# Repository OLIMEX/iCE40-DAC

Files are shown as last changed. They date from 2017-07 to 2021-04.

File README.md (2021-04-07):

# iCE40-DAC
Extension module for iCE40HX1K-EVB or iCE40HX8K-EVB.

Adds fast Digital-Analog-Converter (DAC) functionality to the main board.

You can effectively use up to 4 x iCE40-DAC with a single EVB board (or up to 2 x iCE40-DAC when you have iCE40-IO connected to the same bus).

You can use the exported PDFs to access the schematic or the bill of materials. 

We used the latest KiCad night builds to create the design. Please use a new version KiCad to open it. 

License information should be found in LICENSE.txt

## Hardware revision changes:

### Hardware revision A1

- Changed resistor changing R9 to 0R (down from 10k), this is done because EXTIO was not properly grounded leading to wrong levels

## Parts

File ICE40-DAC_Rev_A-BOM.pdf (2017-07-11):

ICE40-DAC_Rev_A-BOM | 30.03.2016
Quantity Designation | Package | Designator
1 | BH34R | BH34R | GPIO_Out1
2 | 22uF/6.3V/0603 | C_0603 | C1,C4
6 | 100nF | C_0402 | C2,C5,C6,C10,C3,C13
2 | 49.9R/1% | R_0603 | R11,R12
1 | 2k/1% | R_0402 | R10
2 | 10k | R_0402 | R4,R9
1 | 22R | R_0402 | R6
2 | FB0805/600R/2A | L_0805 | L1,L2
1 | SN74ACT244DWR(SOIC-20) | SOIC20 | U2
1 | THS5641AIDW(SOIC28) | SOIC28-300 | U1
1 | IDC34R | IDC34R_PCB | GPIO_In1
1 | BNC-JD11-50-LF | BNC-JD11-50-LF | IOUT1
1 | Soldered | SJ | CLK_E1
3 | Opened | SJ | CLK_E2,CLK_E3,CLK_E4
1 | NA(HN1x2) | HN1x2 | IOUT2
1 | NA(BC817-40(SOT-23)) | SOT23 | Q1
2 | NA(22uF/6.3V/0603) | C_0603 | C8,C7
3 | NA | C_0402 | C12,C9,C11
6 | NA | R_0402 | R1,R2,R3,R5,R7,R8
1 | NA(TLV431BSN1T1G(SOT23-3)) | SOT-23-3 | SR1

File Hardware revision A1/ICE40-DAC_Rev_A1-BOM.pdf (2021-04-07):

02/19/2021 | ICE40-DAC_Rev_A1-BOM | 16:56:18
Quantity | Designation | Package | Designator
1 | 0R | R_0402 | R9
1 | 22R | R_0402 | R6
2 | 49.9R/1% | R_0603 | R11,R12
1 | 2k/1% | R_0402 | R10
1 | 10k | R_0402 | R4
2 | FB0805/600R/2A | L_0805 | L1,L2
6 | 100nF | C_0402 | C2,C3,C5,C6,C10,C13
2 | 22uF/6.3V/0603 | C_0603 | C1,C4
1 | SN74ACT244DWR(SOIC-20) | SOIC20 | U2
1 | THS5641AIDW(SOIC28) | SOIC28-300 | U1
1 | BH34R | BH34R | GPIO_Out1
1 | IDC34R | IDC34R_PCB | GPIO_In1
1 | BNC-JD11-50-LF | BNC-JD11-50-LF | IOUT1
1 | Soldered | SJ | CLK_E1
3 | Opened | SJ | CLK_E2,CLK_E3,CLK_E4
1 | NA(HN1x2) | HN1x2 | IOUT2
1 | NA(BC817-40(SOT-23)) | SOT23 | Q1
2 | NA(22uF/6.3V/0603) | C_0603 | C7,C8
3 | NA | C_0402 | C9,C11,C12
6 | NA | R_0402 | R1,R2,R3,R5,R7,R8
1 | NA(TLV431BSN1T1G(SOT23-3)) | SOT-23-3 | SR1

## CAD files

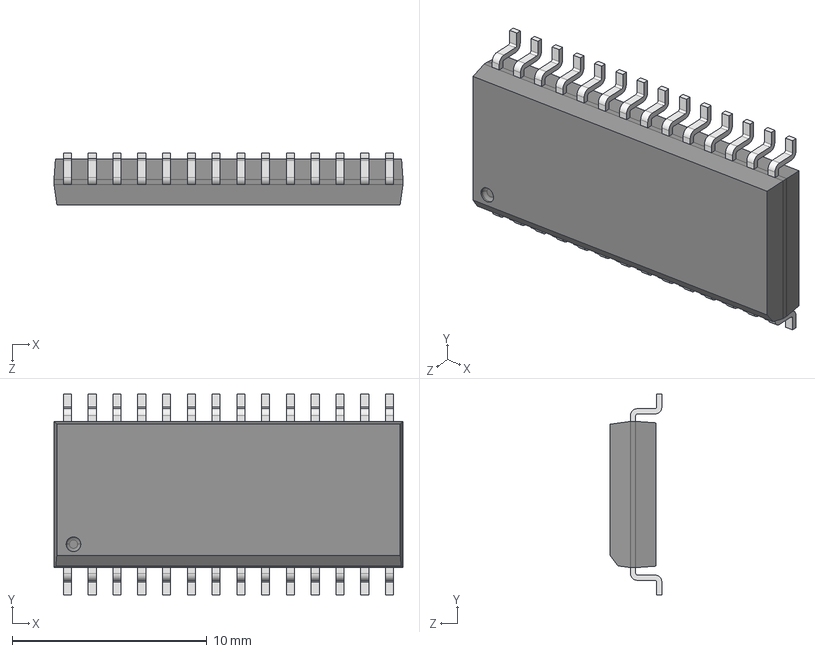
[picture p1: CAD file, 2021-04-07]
Hardware revision A1/3d/SOIC28-300.step
17.9 x 10.3 x 2.65 mm

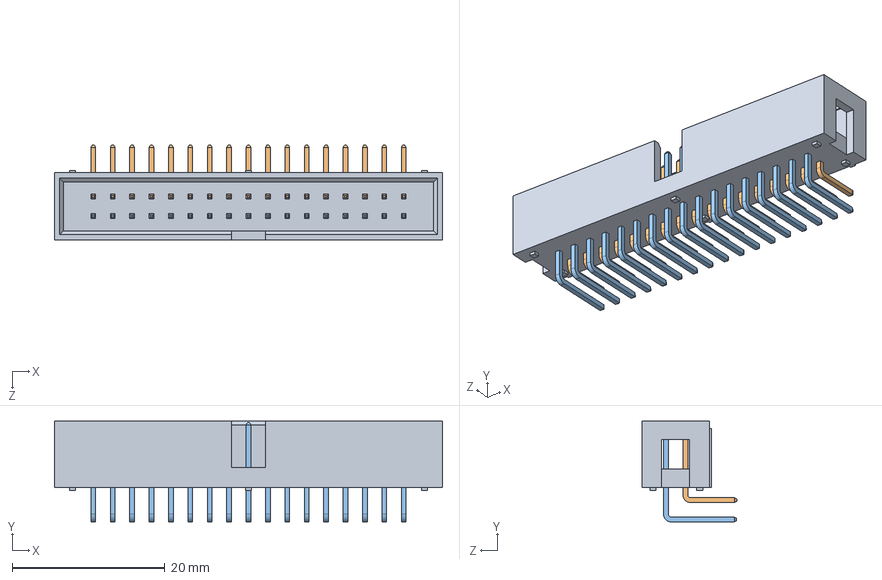
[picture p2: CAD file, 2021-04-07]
Hardware revision A1/3d/BH34R_CH87342H100.STEP
50.8 x 13.2 x 12.4 mm
CH87 BASE_34
H TYPEµuPIN x 17
H TYPEªøPIN x 17

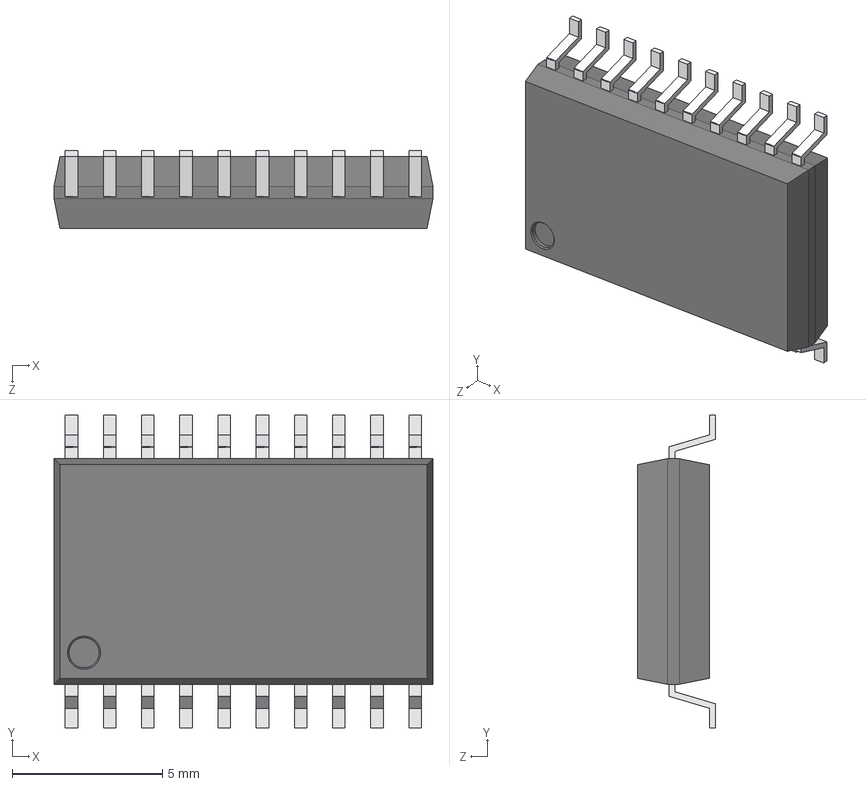
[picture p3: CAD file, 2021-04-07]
Hardware revision A1/3d/SOIC_20-300.STEP
12.6 x 10.4 x 2.60 mm
User Library-SOIC_20-300_pino1
User Library-SOIC_20-300_pino002
User Library-SOIC_20-300_pino003
User Library-SOIC_20-300_pino004
User Library-SOIC_20-300_pino005
User Library-SOIC_20-300_pino006
User Library-SOIC_20-300_pino007
User Library-SOIC_20-300_pino008
User Library-SOIC_20-300_pino009
User Library-SOIC_20-300_pino010
User Library-SOIC_20-300_pino015
User Library-SOIC_20-300_pino016
User Library-SOIC_20-300_pino017
User Library-SOIC_20-300_pino018
User Library-SOIC_20-300_pino019
User Library-SOIC_20-300_pino020
User Library-SOIC_20-300_pino021
User Library-SOIC_20-300_pino022
User Library-SOIC_20-300_pino023
User Library-SOIC_20-300_pino024
User Library-SOIC_20-300_body_finished

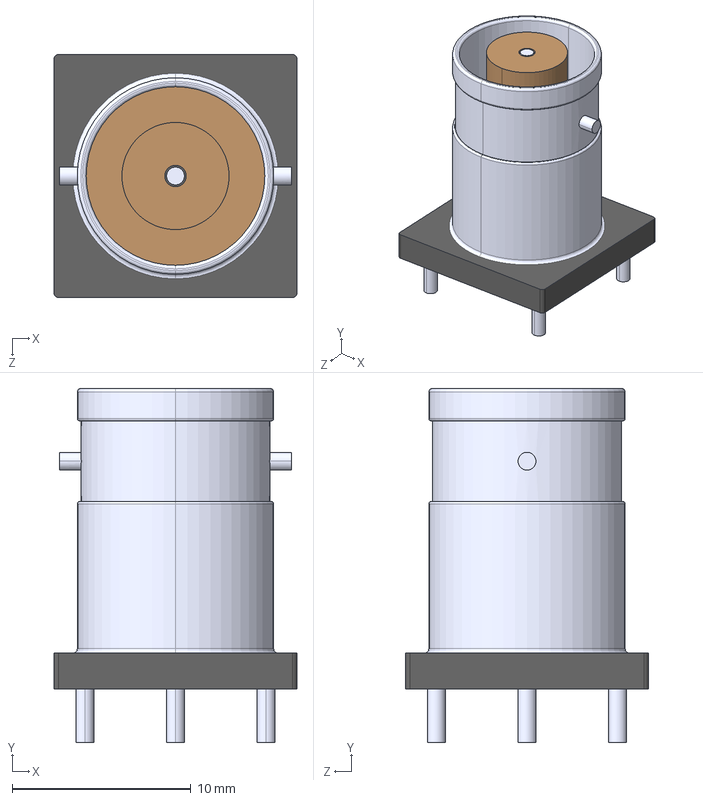
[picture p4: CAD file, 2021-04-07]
Hardware revision A1/3d/CircuitWorks-BNC.step
13.6 x 19.8 x 13.6 mm

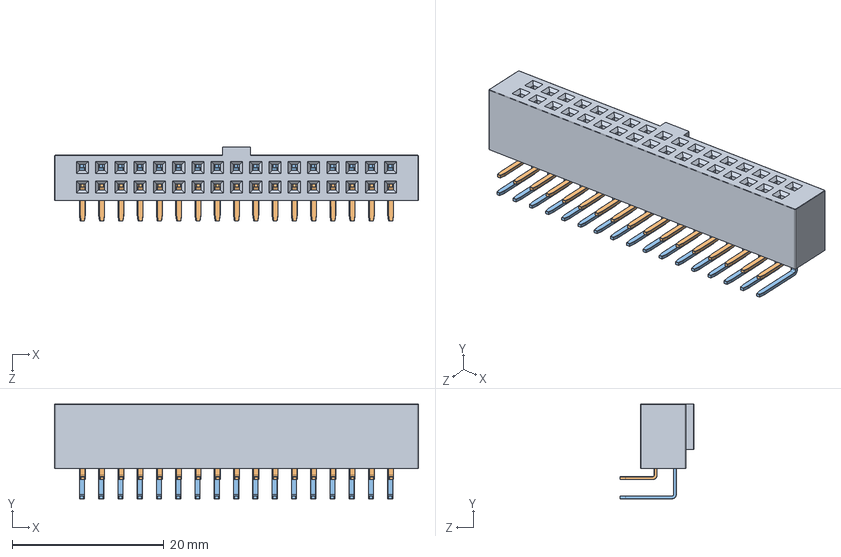
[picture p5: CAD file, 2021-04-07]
Hardware revision A1/3d/IDC34R-PCB_CB94342H100.STEP
48.0 x 12.5 x 9.81 mm
cb94 BASE_34
CB91-t2 x 17
CB91-t3 x 17

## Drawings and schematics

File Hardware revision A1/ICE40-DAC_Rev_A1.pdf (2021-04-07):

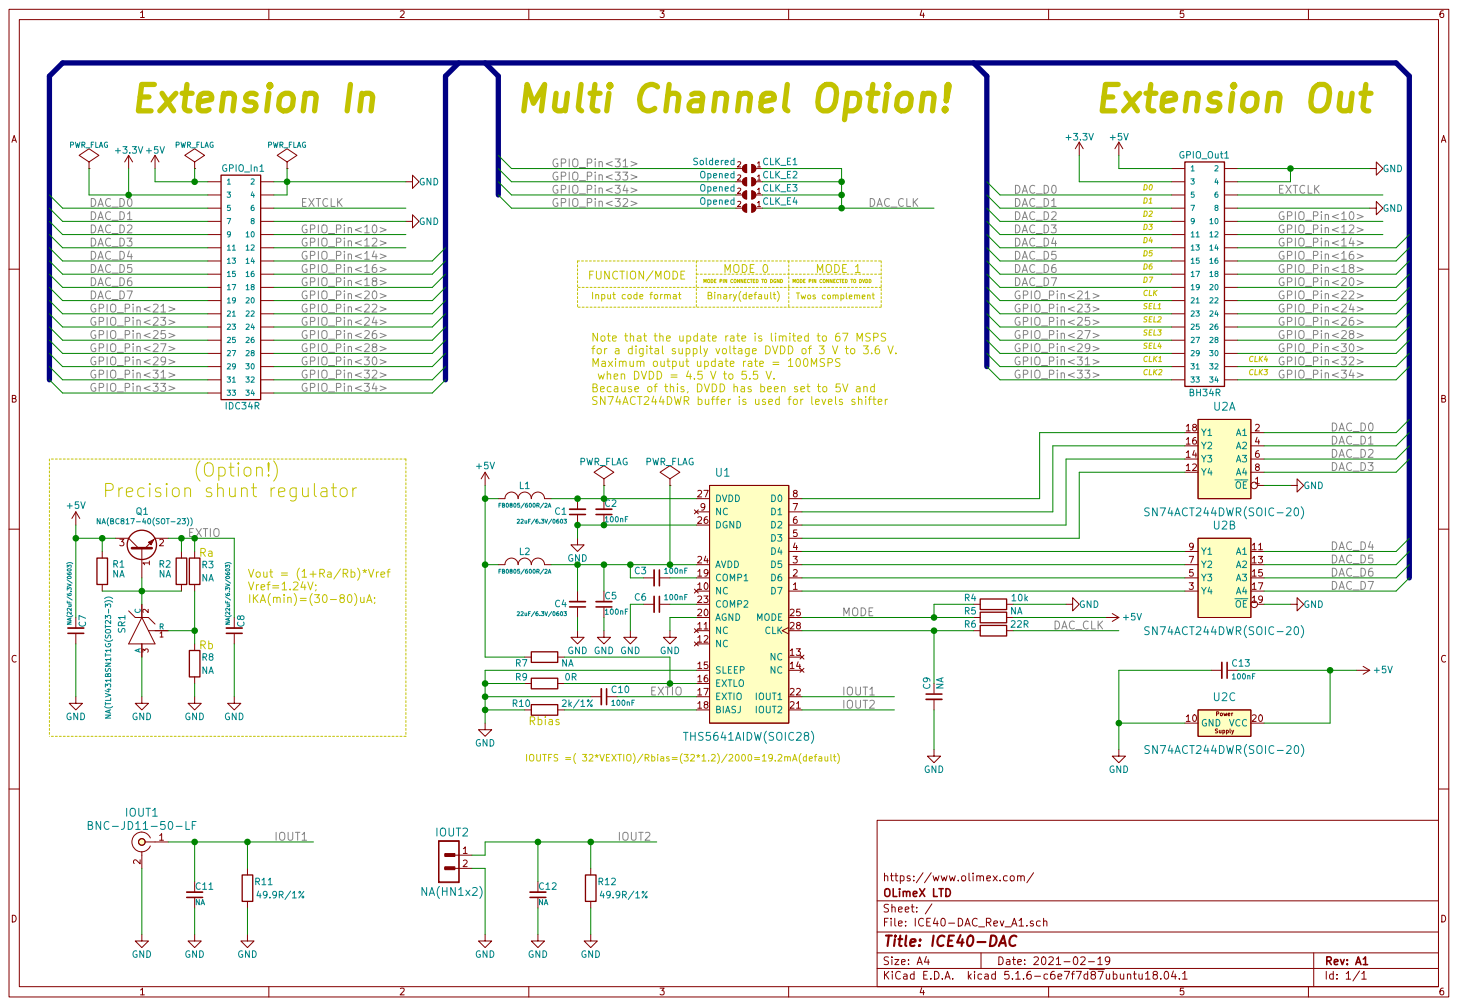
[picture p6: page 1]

Note that the update rate is limited to 67 MSPS
for a digital supply voltage DVDD of 3 V to 3.6 V.
Maximum output update rate = 100MSPS
when DVDD = 4.5 V to 5.5 V. Because of this, DVDD has been set to 5V and

(Option!)
Precision shunt regulator Rb

https://www.olimex.com/ GND

Vout = (1+Ra/Rb)*Vref
Vref=1.24V;
IKA(min)=(30-80)uA;

IOUT2

IOUTFS =( 32*VEXTIO)/Rbias=(32*1.2)/2000=19.2mA(default)

File: ICE40-DAC_Rev_A1.sch Sheet: / OLimeX LTD

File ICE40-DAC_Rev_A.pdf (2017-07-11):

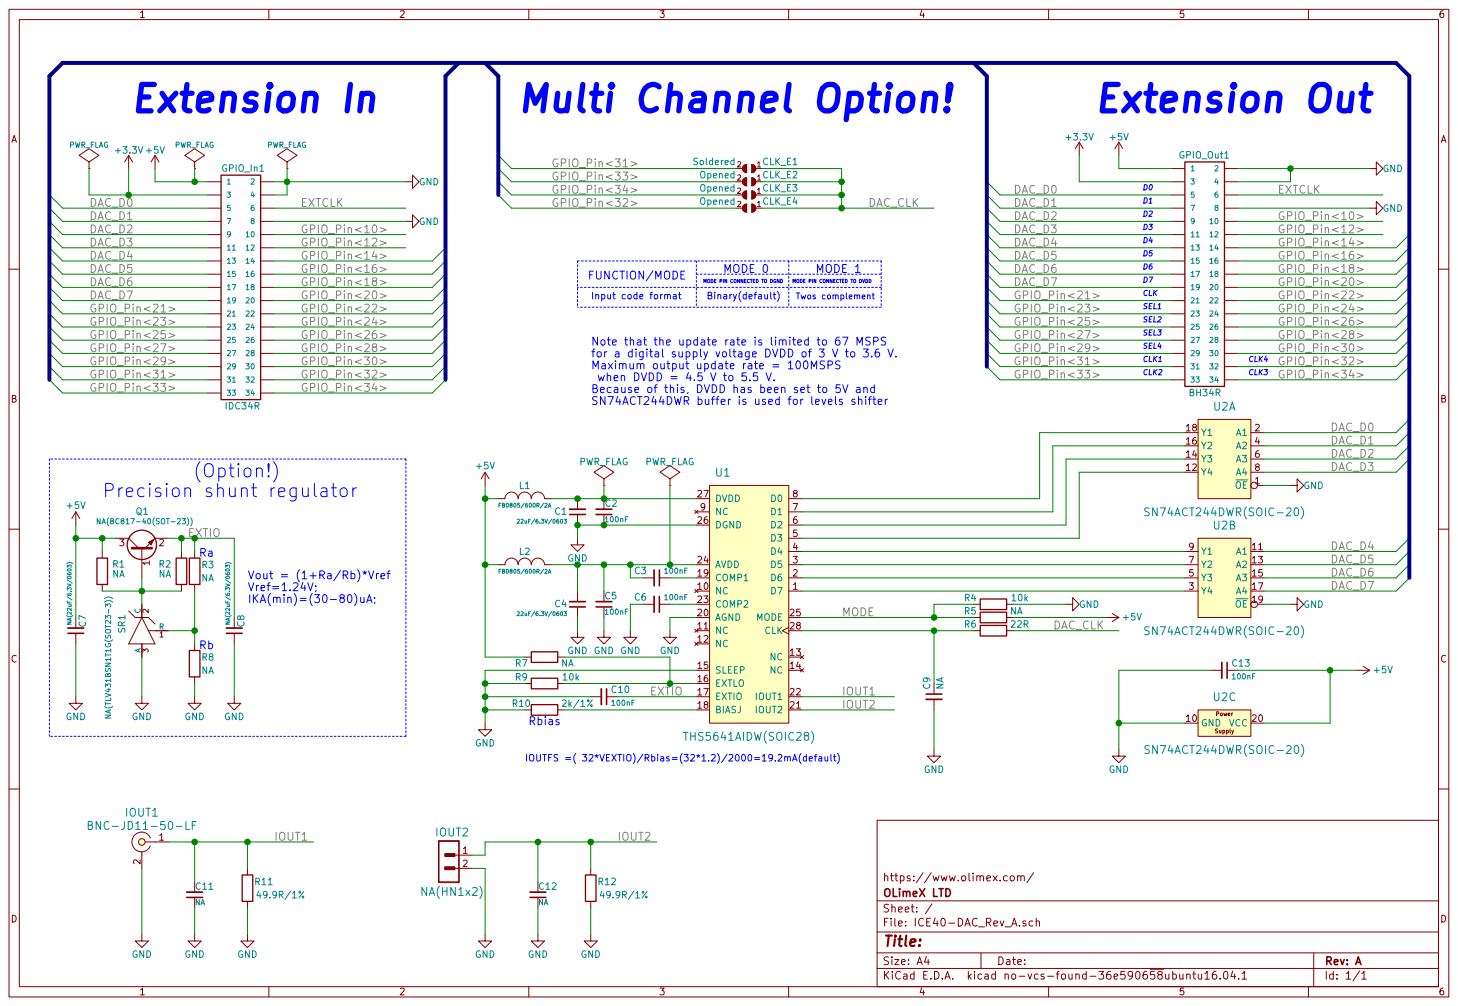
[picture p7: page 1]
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

SN74ACT244DWR buffer is used for levels shifter Rbias

IKA(min)=(30-80)uA; Ra Rb GND

IOUT2

IOUTFS =( 32*VEXTIO)/Rbias=(32*1.2)/2000=19.2mA(default)

https://www.olimex.com/
File: ICE40-DAC_Rev_A.sch Sheet: / OLimeX LTD

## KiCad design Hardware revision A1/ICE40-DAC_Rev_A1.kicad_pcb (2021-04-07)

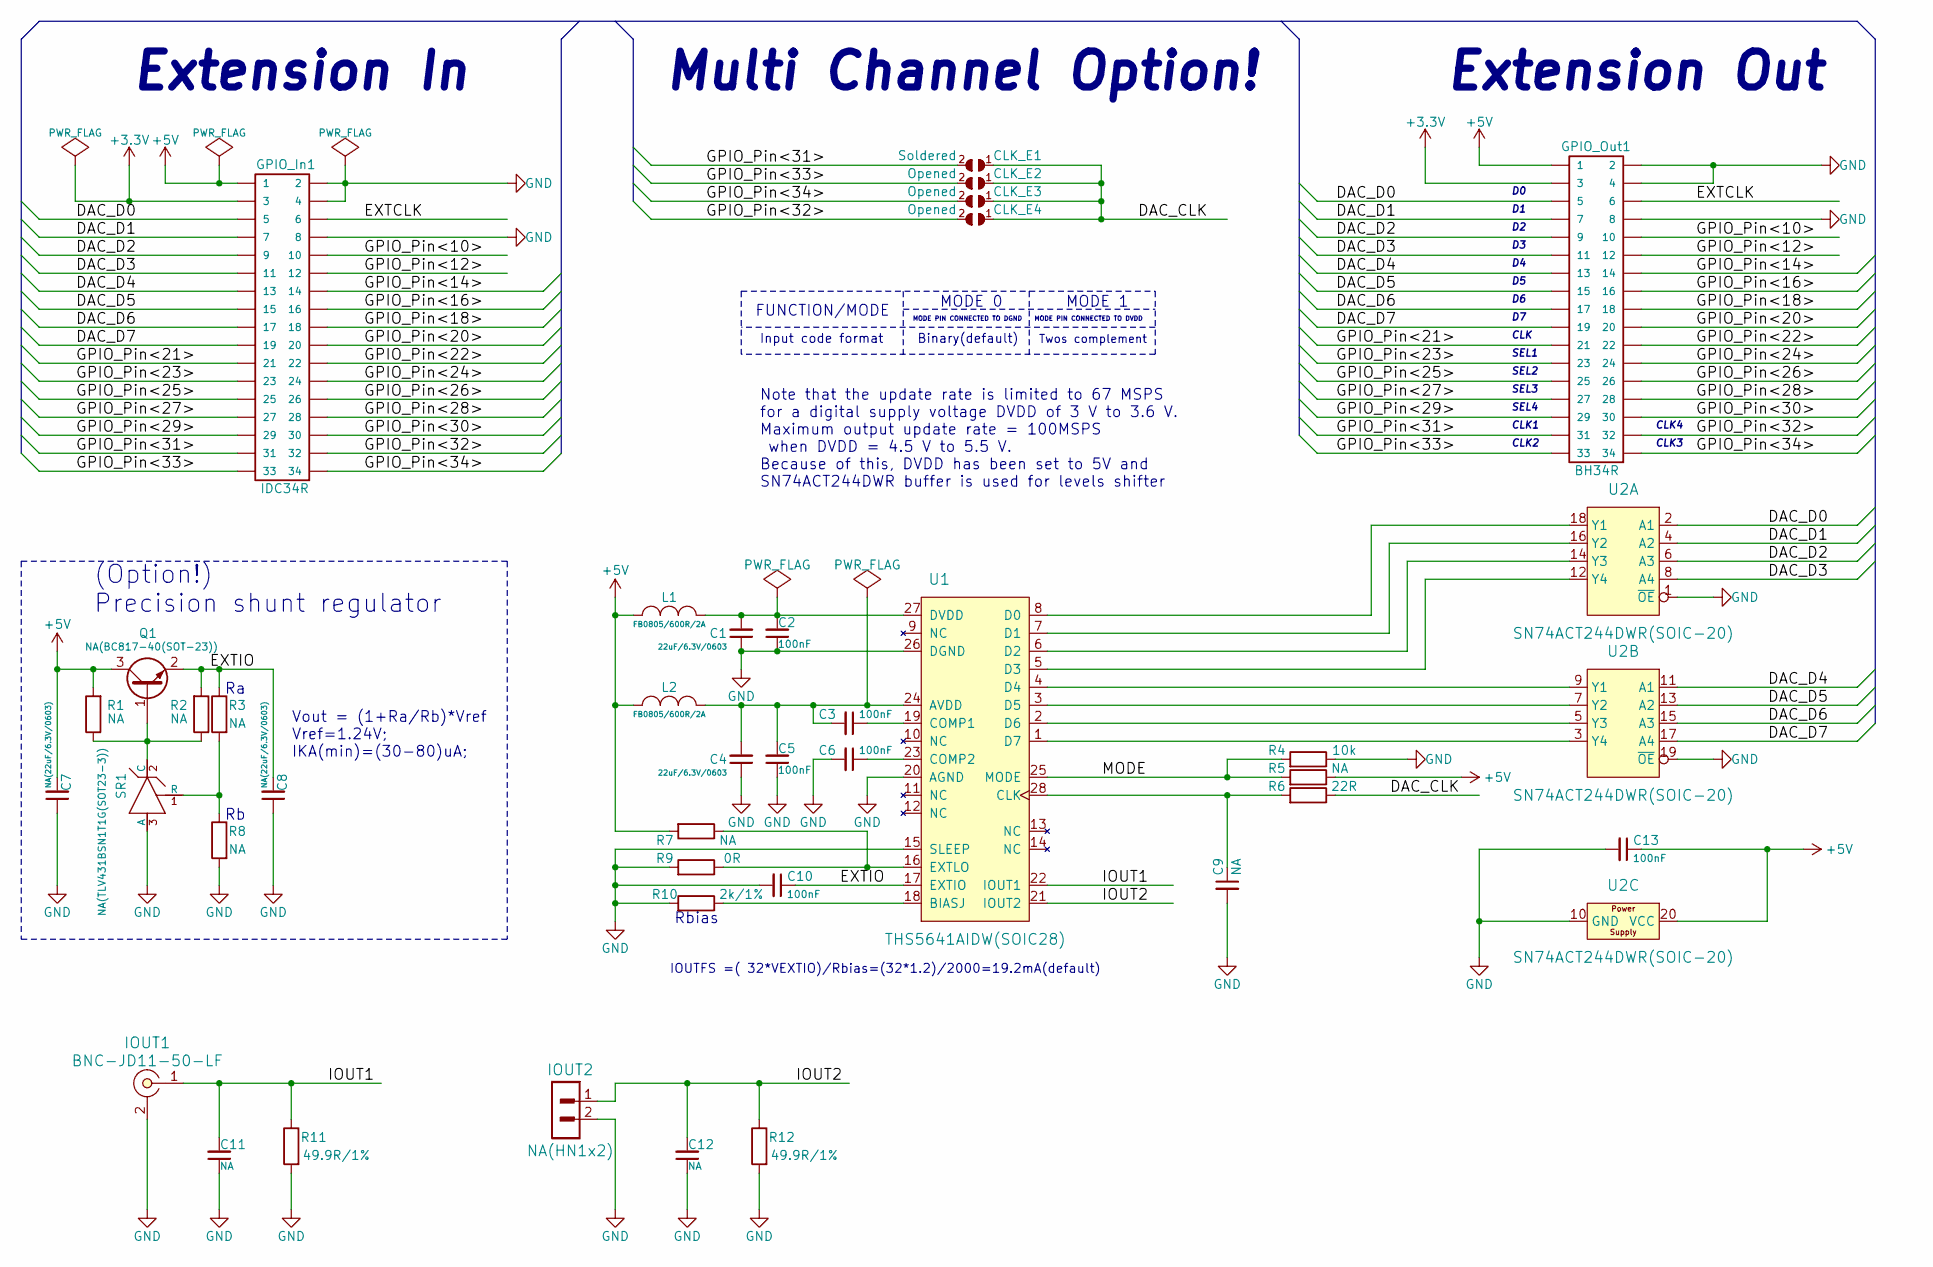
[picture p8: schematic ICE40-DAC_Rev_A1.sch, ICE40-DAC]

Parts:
C1, C4: 22uF/6.3V/0603; C_0603_5MIL_DWS
C2, C3, C5, C6, C10, C13: 100nF; C_0402_5MIL_DWS
C7, C8: NA(22uF/6.3V/0603); C_0603_5MIL_DWS
C9, C11, C12: NA; C_0402_5MIL_DWS
CLK_E1: Soldered; SJ
CLK_E2, CLK_E3, CLK_E4: Opened; SJ
GPIO_In1: IDC34R; IDC34R_PCB
GPIO_Out1: BH34R
IOUT1: BNC-JD11-50-LF; BNC-JD11-50-LF_1-IN_2-GND
IOUT2: NA(HN1x2); HN1x2
L1, L2: FB0805/600R/2A; L_0805_5MIL_DWS
Q1: NA(BC817-40(SOT-23)); SOT23
R1, R2, R3, R5, R7, R8: NA; R_0402_5MIL_DWS
R4: 10k; R_0402_5MIL_DWS
R6: 22R; R_0402_5MIL_DWS
R9: 0R; R_0402_5MIL_DWS
R10: 2k/1%; R_0402_5MIL_DWS
R11, R12: 49.9R/1%; R_0603_5MIL_DWS
SR1: NA(TLV431BSN1T1G(SOT23-3)); SOT-23
U1: THS5641AIDW(SOIC28); SOIC28-300
U2: SN74ACT244DWR(SOIC-20); SOIC20_300mil

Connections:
+3V3: GPIO_In1.3, GPIO_Out1.3
+5V: C7.2, C13.1, GPIO_In1.1, GPIO_Out1.1, L1.2, L2.1, Q1.3 (C), R1.2, R5.1, R7.2, U2.20 (VCC)
/DAC_CLK: CLK_E1.1, CLK_E2.1, CLK_E3.1, CLK_E4.1, R6.1
/DAC_D0: GPIO_In1.5, GPIO_Out1.5, U2.2 (A1)
/DAC_D1: GPIO_In1.7, GPIO_Out1.7, U2.4 (A2)
/DAC_D2: GPIO_In1.9, GPIO_Out1.9, U2.6 (A3)
/DAC_D3: GPIO_In1.11, GPIO_Out1.11, U2.8 (A4)
/DAC_D4: GPIO_In1.13, GPIO_Out1.13, U2.11 (A1)
/DAC_D5: GPIO_In1.15, GPIO_Out1.15, U2.13 (A2)
/DAC_D6: GPIO_In1.17, GPIO_Out1.17, U2.15 (A3)
/DAC_D7: GPIO_In1.19, GPIO_Out1.19, U2.17 (A4)
/EXTCLK: GPIO_In1.6, GPIO_Out1.6
/EXTIO: C8.2, C10.1, Q1.2 (E), R2.2, R3.1, U1.17 (EXTIO)
/GPIO_Pin<10>: GPIO_In1.10, GPIO_Out1.10
/GPIO_Pin<12>: GPIO_In1.12, GPIO_Out1.12
/GPIO_Pin<14>: GPIO_In1.14, GPIO_Out1.14
/GPIO_Pin<16>: GPIO_In1.16, GPIO_Out1.16
/GPIO_Pin<18>: GPIO_In1.18, GPIO_Out1.18
/GPIO_Pin<20>: GPIO_In1.20, GPIO_Out1.20
/GPIO_Pin<21>: GPIO_In1.21, GPIO_Out1.21
/GPIO_Pin<22>: GPIO_In1.22, GPIO_Out1.22
/GPIO_Pin<23>: GPIO_In1.23, GPIO_Out1.23
/GPIO_Pin<24>: GPIO_In1.24, GPIO_Out1.24
/GPIO_Pin<25>: GPIO_In1.25, GPIO_Out1.25
/GPIO_Pin<26>: GPIO_In1.26, GPIO_Out1.26
/GPIO_Pin<27>: GPIO_In1.27, GPIO_Out1.27
/GPIO_Pin<28>: GPIO_In1.28, GPIO_Out1.28
/GPIO_Pin<29>: GPIO_In1.29, GPIO_Out1.29
/GPIO_Pin<30>: GPIO_In1.30, GPIO_Out1.30
/GPIO_Pin<31>: CLK_E1.2, GPIO_In1.31, GPIO_Out1.31
/GPIO_Pin<32>: CLK_E4.2, GPIO_In1.32, GPIO_Out1.32
/GPIO_Pin<33>: CLK_E2.2, GPIO_In1.33, GPIO_Out1.33
/GPIO_Pin<34>: CLK_E3.2, GPIO_In1.34, GPIO_Out1.34
/IOUT1: C11.2, IOUT1.1, R11.1, U1.22 (IOUT1)
/IOUT2: C12.2, IOUT2.1, R12.1, U1.21 (IOUT2)
/MODE: R4.2, R5.2, U1.25 (MODE)
GND: C1.1, C2.1, C4.1, C5.1, C6.2, C7.1, C8.1, C9.2, C10.2, C11.1, C12.1, C13.2, GPIO_In1.2, GPIO_In1.4, GPIO_In1.8, GPIO_Out1.2, GPIO_Out1.4, GPIO_Out1.8, IOUT1.2, IOUT2.2, R4.1, R8.2, R9.2, R10.2, R11.2, R12.2, SR1.3 (A), U1.15 (SLEEP), U1.20 (AGND), U1.26 (DGND), U2.1 (~OE), U2.10 (GND), U2.19 (~OE)
unnamed: C1.2, C2.2, L1.1, U1.27 (DVDD)
unnamed: C3.1, U1.19 (COMP1)
unnamed: C3.2, C4.2, C5.2, L2.2, U1.24 (AVDD)
unnamed: C6.1, U1.23 (COMP2)
unnamed: C9.1, R6.2, U1.28 (CLK)
unnamed: Q1.1 (B), R1.1, R2.1, SR1.2 (C)
unnamed: R3.2, R8.1, SR1.1 (R)
unnamed: R7.1, R9.1, U1.16 (EXTLO)
unnamed: R10.1, U1.18 (BIASJ)
unnamed: U1.1 (D7), U2.3 (Y4)
unnamed: U1.2 (D6), U2.5 (Y3)
unnamed: U1.3 (D5), U2.7 (Y2)
unnamed: U1.4 (D4), U2.9 (Y1)
unnamed: U1.5 (D3), U2.12 (Y4)
unnamed: U1.6 (D2), U2.14 (Y3)
unnamed: U1.7 (D1), U2.16 (Y2)
unnamed: U1.8 (D0), U2.18 (Y1)

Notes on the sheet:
Extension Out
Extension In
Vout = (1+Ra/Rb)*Vref Vref=1.24V; IKA(min)=(30-80)uA;
(Option!) Precision shunt regulator
Multi Channel Option!
CLK
SEL1
SEL2
SEL3
SEL4
Note that the update rate is limited to 67 MSPS for a digital supply voltage DVDD of 3 V to 3.6 V. Maximum output update rate = 100MSPS when DVDD = 4.5 V to 5.5 V. Because of this, DVDD has been set to 5V and SN74ACT244DWR buffer is used for levels shifter
Rbias
IOUTFS =( 32*VEXTIO)/Rbias=(32*1.2)/2000=19.2mA(default)
FUNCTION/MODE
MODE 0
MODE 1
MODE PIN CONNECTED TO DGND
MODE PIN CONNECTED TO DVDD
Input code format
Binary(default)
Twos complement
CLK1
CLK2
CLK3
CLK4

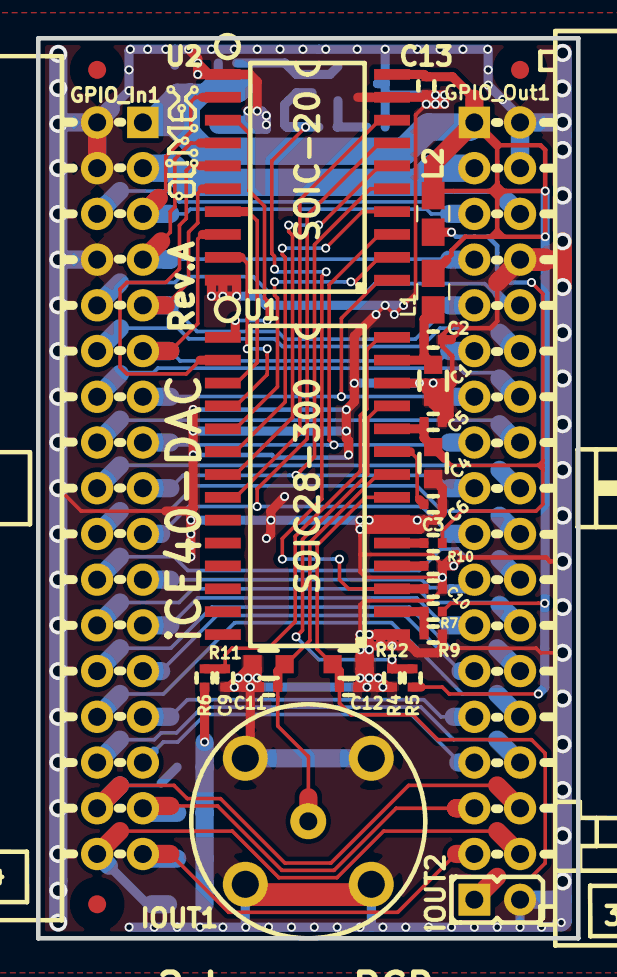
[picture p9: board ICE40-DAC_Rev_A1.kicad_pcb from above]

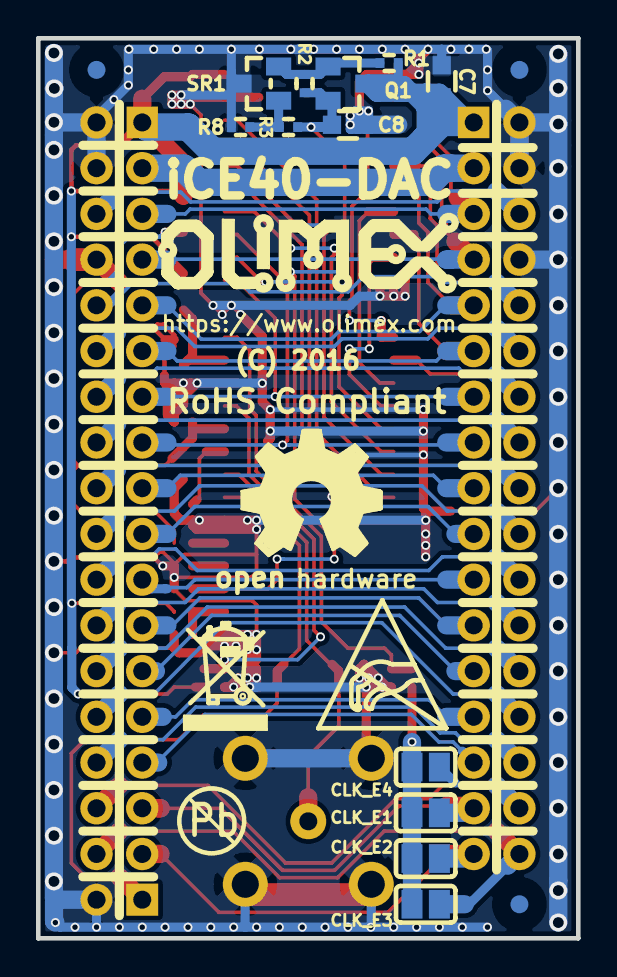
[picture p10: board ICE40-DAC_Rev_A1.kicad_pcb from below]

Board: 2 copper layers, 30.0 x 50.0 mm, 40 parts (13 on the bottom side), 54 nets.

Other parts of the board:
Ref**: Val**; LOGO_ANTISTATIC_1

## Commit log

2017-07-11 Update
    relocate
    [ICE40-DAC_Rev_A.kicad_pcb, ICE40-DAC_Rev_A.sch]
2017-07-11 Update
    Updated trace names
    [ICE40-DAC_Rev_A-BOM.ods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]
2021-04-07 update
    revision A1 and 3d added
    [BH34R_CH87342H100.STEP, CircuitWorks-BNC.step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]

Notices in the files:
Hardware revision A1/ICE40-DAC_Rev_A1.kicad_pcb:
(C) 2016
